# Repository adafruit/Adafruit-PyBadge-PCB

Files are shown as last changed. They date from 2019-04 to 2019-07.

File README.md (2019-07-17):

## Adafruit PyBadge PCB

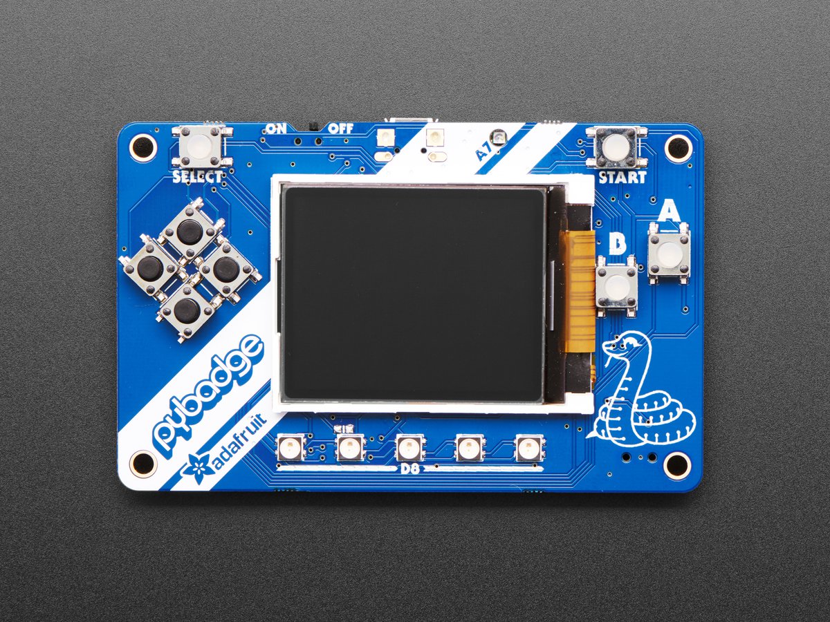
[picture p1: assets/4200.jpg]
<a href="http://www.adafruit.com/products/4200"><br/>
Click here to purchase one from the Adafruit shop</a>

PCB files for the Adafruit PyBadge. 

Format is EagleCAD schematic and board layout
* https://www.adafruit.com/product/4200

### Description

What's the size of a credit card and can run CircuitPython, MakeCode Arcade or Arduino? That's right, its the **Adafruit PyBadge!** We wanted to see how much we could cram into a 3 3⁄8 × 2 1⁄8 inch rounded rectangle, to make an all-in-one dev board with a lot of possibilities, and this is what we came up with.

The PyBadge is a compact board, like we said, it's credit card sized. It's powered by our favorite chip, the ATSAMD51, with 512KB of flash and 192KB of RAM. We add 2 MB of QSPI flash for file storage, handy for images, fonts, sounds, or game assets.

On the front you get a 1.8" 160x128 color TFT display with dimmable backlight - we have fast DMA support for drawing so updates are incredibly fast. There's also 8 silicone-top buttons, they are clicky but have a soft button top so they're nice and grippy. The buttons are arranged to mimic a gaming handheld, with a d-pad, 2 menu-select buttons and 2 fire-action buttons. There's also 5 NeoPixel LEDs to dazzle or track activity.

On the back we have a full Feather-compatible header socket set, so you can plug in any FeatherWing to expand the capabilities of the PyBadge. There's also 3 STEMMA connectors - two 3-pin with ADC/PWM capability and one 4-pin that connects to I2C - you can use this for Grove sensors as well.

For built in sensors, there's a light sensor that points out the front, and a 3-axis accelerometer that can detect taps and free-fall. To make bleeps and bloops, there's a built in buzzer-speaker. [For projects where you need more volume, you can plug in one of our 8 ohm speakers](https://www.adafruit.com/product/3923).

[You can power the PyBadge from any of our LiPoly batteries, but we like this 400mAh one](https://www.adafruit.com/product/3898.) An on-off switch will save battery power when not in use. Or power from the Micro USB port - it will also charge up the battery if one is attached.

Now, how to program it? Well you've got a lot of options!

[MakeCode Arcade is the easiest to start for making games](https://arcade.makecode.com/), you can drag-and-drop blocks and load games over the disk-drive bootloader
[CircuitPython](https://circuitpython.org/board/pybadge/) lets you draw graphics, play wave files and print out text in any fonts - all in Python! There's tons of sensor support as well.
Arduino is low level, powerful, but a little more challenging. [You can use Adafruit Arcada](https://github.com/adafruit/Adafruit_Arcada) to interface with the hardware and it will abstract some of the nitty-gritty details like reading buttons for you.
Here's a list of everything you get

 * **ATSAMD51J19** @ 120MHz with 3.3V logic/power - 512KB of FLASH + 192KB of RAM
 * **2 MB of SPI Flash** for storing images, sounds, animations, whatever!
 * **1.8" 160x128 Color TFT Display** connected to its own SPI port
 * **8 x Game/Control Buttons** with nice silicone button tops (these feel great)
 * **5 x NeoPixels** for badge dazzle, or game score-keeping
 * **Triple-axis accelerometer** (motion sensor)
 * **Light sensor**, reverse-mount so that it points out the front
 * **Built in buzzer mini-speaker**
 * **Mono Class-D speaker driver for** 4-8 ohm speakers, up to 2 Watts
 * LiPoly battery port with built in recharging capability
 * USB port for battery charging, programming and debugging
 * Two female header strips with Feather-compatible pinout so you can plug any FeatherWings in
 * JST ports for NeoPixels, sensor input, and I2C (you can fit I2C Grove connectors in here)
 * Reset button
 * On-Off switch

### License

Adafruit invests time and resources providing this open source design, please support Adafruit and open-source hardware by purchasing products from [Adafruit](https://www.adafruit.com)!

Designed by Limor Fried/Ladyada for Adafruit Industries.

Creative Commons Attribution/Share-Alike, all text above must be included in any redistribution. 
See license.txt for additional details.

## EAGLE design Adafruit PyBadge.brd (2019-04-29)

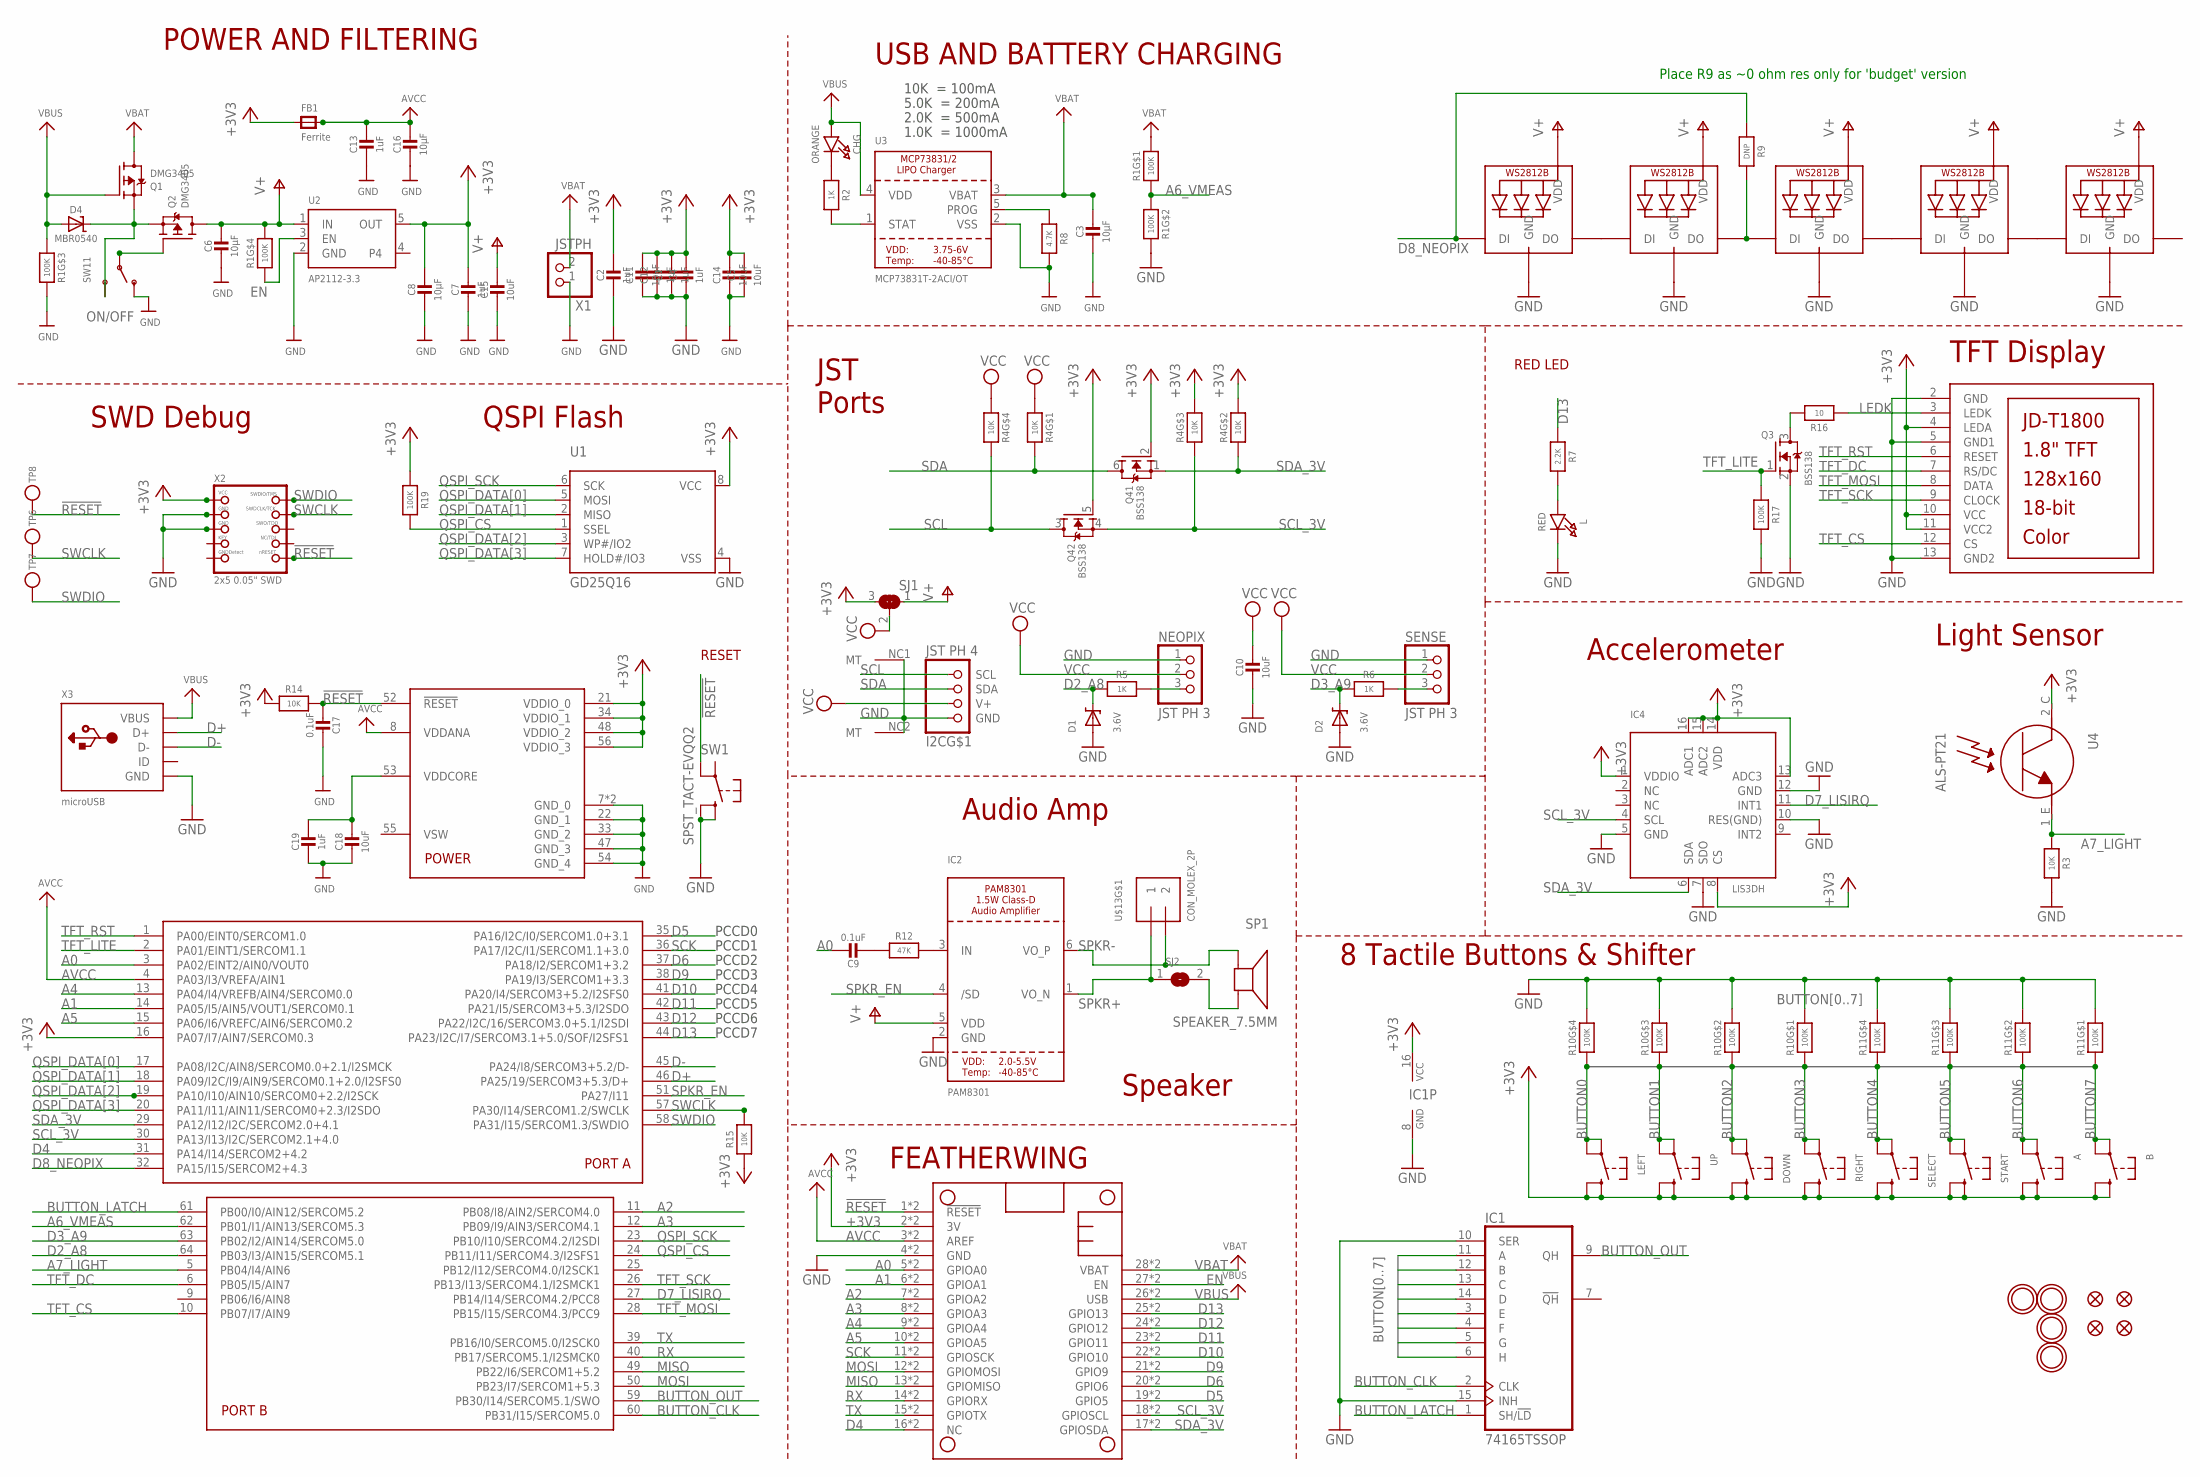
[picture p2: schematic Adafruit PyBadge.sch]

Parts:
A: SWITCH_TACT_SMT_6MMSMALL; 6MM_SMT
B: SWITCH_TACT_SMT_6MMSMALL; 6MM_SMT
C1, C2, C4, C7, C12, C13, C19: 1uF; 0603-NO
C3, C6, C8: 10µF; 0805-NO
C5, C10, C11, C14, C15, C18: 10uF; 0805-NO
C9, C17: 0.1uF; 0603-NO
C16: 10µF; _0805MP
CHG: ORANGE; CHIPLED_0805_NOOUTLINE
D1, D2: 3.6V; SOD-323
D4: MBR0540; SOD-123
DOWN: SWITCH_TACT_SMT_6MMSMALL; 6MM_SMT
FB1: Ferrite; 0805-NO
I2C: JST PH 4; JSTPH4
IC1: 74165TSSOP; TSSOP16
IC2: PAM8301; SOT23-6
IC4: LIS3DH; LGA16_3X3MM
L: RED; CHIPLED_0805_NOOUTLINE
LCD1: DISP_LCD_JDT1800; JD-T1800
LED1, LED2, LED3, LED4, LED5: WS2812B3535; LED3535
LEFT: SWITCH_TACT_SMT_6MMSMALL; 6MM_SMT
MS1: FEATHERWING_SMTDUALNOHOLES; FEATHERWING_SMT_NOHOLES
NEOPIX: JST PH 3; JSTPH3
Q1, Q2: DMG3405; SOT23-R
Q3: BSS138; SOT23-WIDE
Q4: BSS138; SOT363
R1, R10, R11: 100K; RESPACK_4X0603
R2, R5, R6: 1K; 0603-NO
R3, R14, R15: 10K; 0603-NO
R4: 10K; RESPACK_4X0603
R7: 2.2K; 0603-NO
R8: 4.7K; 0603-NO
R9: DNP; 0603-NO
R12: 47K; 0603-NO
R16: 10; 0603-NO
R17, R19: 100K; 0603-NO
RIGHT: SWITCH_TACT_SMT_6MMSMALL; 6MM_SMT
SELECT: SWITCH_TACT_SMT_6MMSMALL; 6MM_SMT
SENSE: JST PH 3; JSTPH3
SJ1: SOLDERJUMPER_2WAY; SOLDERJUMPER_2WAY_OPEN_NOPASTE
SJ2: SOLDERJUMPERCLOSED; SOLDERJUMPER_CLOSEDWIRE
SP1: SPEAKER_7.5MM; BUZZER_SMT_7.5MM
START: SWITCH_TACT_SMT_6MMSMALL; 6MM_SMT
SW1: SPST_TACT-EVQQ2; EVQ-Q2_SMALLER
SW11: SWITCH_SPDT; SPDT_SMT_SSSS811101
TP6, TP7, TP8: TESTPOINTROUND2MM; TESTPOINT_ROUND_2MM
U1: GD25Q16; SOIC8_208MIL
U2: AP2112-3.3; SOT23-5
U3: MCP73831T-2ACI/OT; SOT23-5
U4: ALS-PT21; ALS-PT26-21C
U$5, U$6, U$15, U$17: MOUNTINGHOLE3.0THIN; MOUNTINGHOLE_3.0_PLATEDTHIN
U$13: CON_MOLEX_2P; 53398-0271
U$24: ATSAMD51J19; PQFN64-1
U$34, U$35, U$42, U$43: FIDUCIAL_1MM
UP: SWITCH_TACT_SMT_6MMSMALL; 6MM_SMT
X1: JSTPH; JSTPH2
X2: 2x5 0.05" SWD; 2X05_1.27MM_BOX_POSTS
X3: microUSB; 4UCONN_20329_V2

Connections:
!RESET: C17.2, MS1.1 (!RESET), MS1.1B (!RESET), R14.2, SW1.A' (P1), TP8.P$1, U$24.52 (!RESET), X2.10 (NRESET)
+3V3: A.B (S), A.B' (S1), B.B (S), B.B' (S1), C1.1, C2.1, C4.1, C5.1, C7.1, C8.1, C11.1, C12.1, C14.1, DOWN.B (S), DOWN.B' (S1), FB1.1, IC1.16 (VCC), IC4.1 (VDDIO), IC4.8 (CS), IC4.13 (ADC3), IC4.14 (VDD), IC4.15 (ADC2), IC4.16 (ADC1), LCD1.4 (LEDA), LCD1.10 (VCC), LCD1.11 (VCC2), LEFT.B (S), LEFT.B' (S1), MS1.2 (3V), MS1.2B (3V), Q4.2 (G), Q4.5 (G), R4.2 (1), R4.3 (1), R14.1, R15.1, R19.1, RIGHT.B (S), RIGHT.B' (S1), SELECT.B (S), SELECT.B' (S1), SJ1.3, START.B (S), START.B' (S1), U1.8 (VCC), U2.5 (OUT), U4.2_C (C), U$24.16 (PA07/I7/AIN7/SERCOM0.3), U$24.21 (VDDIO_0), U$24.34 (VDDIO_1), U$24.48 (VDDIO_2), U$24.56 (VDDIO_3), UP.B (S), UP.B' (S1), X2.1 (VCC)
A0: C9.1, MS1.5 (GPIOA0), MS1.5B (GPIOA0), U$24.3 (PA02/EINT2/AIN0/VOUT0)
A1: MS1.6 (GPIOA1), MS1.6B (GPIOA1), U$24.14 (PA05/I5/AIN5/VOUT1/SERCOM0.1)
A2: MS1.7 (GPIOA2), MS1.7B (GPIOA2), U$24.11 (PB08/I8/AIN2/SERCOM4.0)
A3: MS1.8 (GPIOA3), MS1.8B (GPIOA3), U$24.12 (PB09/I9/AIN3/SERCOM4.1)
A4: MS1.9 (GPIOA4), MS1.9B (GPIOA4), U$24.13 (PA04/I4/VREFB/AIN4/SERCOM0.0)
A5: MS1.10 (GPIOA5), MS1.10B (GPIOA5), U$24.15 (PA06/I6/VREFC/AIN6/SERCOM0.2)
A6_VMEAS: R1.1, R1.2 (1), U$24.62 (PB01/I1/AIN13/SERCOM5.3)
A7_LIGHT: R3.2, U4.1_E (E), U$24.5 (PB04/I4/AIN6)
AVCC: C13.1, C16.1, FB1.2, MS1.3 (AREF), MS1.3B (AREF), U$24.4 (PA03/I3/VREFA/AIN1), U$24.8 (VDDANA)
BUTTON0: IC1.11 (A), LEFT.A, LEFT.A' (P1), R10.4 (1)
BUTTON1: IC1.12 (B), R10.3 (1), UP.A, UP.A' (P1)
BUTTON2: DOWN.A, DOWN.A' (P1), IC1.13 (C), R10.2 (1)
BUTTON3: IC1.14 (D), R10.1, RIGHT.A, RIGHT.A' (P1)
BUTTON4: IC1.3 (E), R11.4 (1), SELECT.A, SELECT.A' (P1)
BUTTON5: IC1.4 (F), R11.3 (1), START.A, START.A' (P1)
BUTTON6: A.A, A.A' (P1), IC1.5 (G), R11.2 (1)
BUTTON7: B.A, B.A' (P1), IC1.6 (H), R11.1
BUTTON_CLK: IC1.2 (CLK), U$24.60 (PB31/I15/SERCOM5.0)
BUTTON_LATCH: IC1.1 (SH/!LD), U$24.61 (PB00/I0/AIN12/SERCOM5.2)
BUTTON_OUT: IC1.9 (QH), U$24.59 (PB30/I14/SERCOM5.1/SWO)
CHG_LED: R2.2, U3.1 (STAT)
CHG_RATE: R8.1, U3.5 (PROG)
D2_: NEOPIX.3, R5.1
D2_A8: D1.C, R5.2, U$24.64 (PB03/I3/AIN15/SERCOM5.1)
D3_: R6.1, SENSE.3
D3_A9: D2.C, R6.2, U$24.63 (PB02/I2/AIN14/SERCOM5.0)
D4: MS1.16 (NC), MS1.16B (NC), U$24.31 (PA14/I14/SERCOM2+4.2)
D5: MS1.19 (GPIO5), MS1.19B (GPIO5), U$24.35 (PA16/I2C/I0/SERCOM1.0+3.1)
D6: MS1.20 (GPIO6), MS1.20B (GPIO6), U$24.37 (PA18/I2/SERCOM1+3.2)
D7_LISIRQ: IC4.11 (INT1), U$24.27 (PB14/I14/SERCOM4.2/PCC8)
D8_NEOPIX: LED1.1 (DI), R9.1, U$24.32 (PA15/I15/SERCOM2+4.3)
D9: MS1.21 (GPIO9), MS1.21B (GPIO9), U$24.38 (PA19/I3/SERCOM1+3.3)
D10: MS1.22 (GPIO10), MS1.22B (GPIO10), U$24.41 (PA20/I4/SERCOM3+5.2/I2SFS0)
D11: MS1.23 (GPIO11), MS1.23B (GPIO11), U$24.42 (PA21/I5/SERCOM3+5.3/I2SDO)
D12: MS1.24 (GPIO12), MS1.24B (GPIO12), U$24.43 (PA22/I2C/16/SERCOM3.0+5.1/I2SDI)
D13: MS1.25 (GPIO13), MS1.25B (GPIO13), R7.1, U$24.44 (PA23/I2C/I7/SERCOM3.1+5.0/SOF/I2SFS1)
D+: U$24.46 (PA25/19/SERCOM3+5.3/D+), X3.D+
D-: U$24.45 (PA24/I8/SERCOM3+5.2/D-), X3.D-
EN: MS1.27 (EN), MS1.27B (EN), R1.4 (1), U2.3 (EN)
GND: C1.2, C2.2, C3.2, C4.2, C5.2, C6.2, C7.2, C8.2, C10.2, C11.2, C12.2, C13.2, C14.2, C15.2, C16.2, C17.1, C18.2, C19.2, D1.A, D2.A, I2C.1 (GND), I2C.NC1 (MT), I2C.NC2 (MT), IC1.8 (GND), IC1.10 (SER), IC1.15 (INH), IC2.2 (GND), IC4.5 (GND), IC4.7 (SDO), IC4.10 (RES(GND)), IC4.12 (GND), L.C, LCD1.2 (GND), LCD1.5 (GND1), LCD1.13 (GND2), LED1.4 (GND), LED2.4 (GND), LED3.4 (GND), LED4.4 (GND), LED5.4 (GND), MS1.4 (GND), MS1.4B (GND), NEOPIX.1, Q3.2 (S), R1.6 (2), R1.7 (2), R3.1, R8.2, R10.5 (2), R10.6 (2), R10.7 (2), R10.8 (2), R11.5 (2), R11.6 (2), R11.7 (2), R11.8 (2), R17.2, SENSE.1, SW1.B (S), SW1.B' (S1), SW11.A (O), U1.4 (VSS), U2.2 (GND), U3.2 (VSS), U$24.7 (GND_0), U$24.22 (GND_1), U$24.33 (GND_2), U$24.47 (GND_3), U$24.54 (GND_4), U$24.EXP (GND_0), X1.1, X2.3 (GND), X2.5 (GND), X3.BASE@1 (GND), X3.BASE@2 (GND), X3.GND, X3.SPRT@1 (GND), X3.SPRT@2 (GND), X3.SPRT@3 (GND), X3.SPRT@4 (GND)
LEDK: LCD1.3 (LEDK), R16.1
MISO: MS1.13 (GPIOMISO), MS1.13B (GPIOMISO), U$24.49 (PB22/I6/SERCOM1+5.2)
MOSI: MS1.12 (GPIOMOSI), MS1.12B (GPIOMOSI), U$24.50 (PB23/I7/SERCOM1+5.3)
unnamed: CHG.C, R2.1
unnamed: L.A, R7.2
unnamed: LED1.3 (DO), LED2.1 (DI)
unnamed: LED2.3 (DO), LED3.1 (DI), R9.2
unnamed: LED3.3 (DO), LED4.1 (DI)
unnamed: Q3.3 (D), R16.2
unnamed: LED4.3 (DO), LED5.1 (DI)
unnamed: D4.C, Q1.2 (S), Q2.2 (S), SW11.C (S)
unnamed: C9.2, R12.1
unnamed: IC2.3 (IN), R12.2
unnamed: SJ2.2, SP1.-
ON/OFF: Q2.1 (G), SW11.B
QSPI_CS: R19.2, U1.1 (SSEL), U$24.24 (PB11/I11/SERCOM4.3/I2SFS1)
QSPI_DATA[0]: U1.5 (MOSI), U$24.17 (PA08/I2C/AIN8/SERCOM0.0+2.1/I2SMCK)
QSPI_DATA[1]: U1.2 (MISO), U$24.18 (PA09/I2C/I9/AIN9/SERCOM0.1+2.0/I2SFS0)
QSPI_DATA[2]: U1.3 (WP#/IO2), U$24.19 (PA10/I10/AIN10/SERCOM0+2.2/I2SCK)
QSPI_DATA[3]: U1.7 (HOLD#/IO3), U$24.20 (PA11/I11/AIN11/SERCOM0+2.3/I2SDO)
QSPI_SCK: U1.6 (SCK), U$24.23 (PB10/I10/SERCOM4.2/I2SDI)
RX: MS1.14 (GPIORX), MS1.14B (GPIORX), U$24.40 (PB17/SERCOM5.1/I2SMCK0)
SCK: MS1.11 (GPIOSCK), MS1.11B (GPIOSCK), U$24.36 (PA17/I2C/I1/SERCOM1.1+3.0)
SCL: I2C.4 (SCL), Q4.3 (D), R4.5 (2)
SCL_3V: IC4.4 (SCL), MS1.18 (GPIOSCL), MS1.18B (GPIOSCL), Q4.4 (S), R4.6 (2), U$24.30 (PA13/I13/I2C/SERCOM2.1+4.0)
SDA: I2C.3 (SDA), Q4.6 (D), R4.8 (2)
SDA_3V: IC4.6 (SDA), MS1.17 (GPIOSDA), MS1.17B (GPIOSDA), Q4.1 (S), R4.7 (2), U$24.29 (PA12/I12/I2C/SERCOM2.0+4.1)
SPKR+: IC2.1 (VO_N), SJ2.1, U$13.1
SPKR-: IC2.6 (VO_P), SP1.+, U$13.2
SPKR_EN: IC2.4 (/SD), U$24.51 (PA27/I11)
SWCLK: R15.2, TP6.P$1, U$24.57 (PA30/I14/SERCOM1.2/SWCLK), X2.4 (SWDCLK)
SWDIO: TP7.P$1, U$24.58 (PA31/I15/SERCOM1.3/SWDIO), X2.2 (SWDIO)
TFT_CS: LCD1.12 (CS), U$24.10 (PB07/I7/AIN9)
TFT_DC: LCD1.7 (RS/DC), U$24.6 (PB05/I5/AIN7)
TFT_LITE: Q3.1 (G), R17.1, U$24.2 (PA01/EINT1/SERCOM1.1)
TFT_MOSI: LCD1.8 (DATA), U$24.28 (PB15/I15/SERCOM4.3/PCC9)
TFT_RST: LCD1.6 (RESET), U$24.1 (PA00/EINT0/SERCOM1.0)
TFT_SCK: LCD1.9 (CLOCK), U$24.26 (PB13/I13/SERCOM4.1/I2SMCK1)
TX: MS1.15 (GPIOTX), MS1.15B (GPIOTX), U$24.39 (PB16/I0/SERCOM5.0/I2SCK0)
V+: C6.1, C15.1, IC2.5 (VDD), LED1.2 (VDD), LED2.2 (VDD), LED3.2 (VDD), LED4.2 (VDD), LED5.2 (VDD), Q2.3 (D), R1.5 (2), SJ1.1, U2.1 (IN)
VBAT: C3.1, MS1.28 (VBAT), MS1.28B (VBAT), Q1.3 (D), R1.8 (2), U3.3 (VBAT), X1.2
VBUS: CHG.A, D4.A, MS1.26 (USB), MS1.26B (USB), Q1.1 (G), R1.3 (1), U3.4 (VDD), X3.VBUS
VCC: C10.1, I2C.2 (V+), NEOPIX.2, R4.1, R4.4 (1), SENSE.2, SJ1.2
VDDCORE2: C18.1, C19.1, U$24.53 (VDDCORE)

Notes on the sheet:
POWER AND FILTERING
RESET
10K = 100mA
5.0K = 200mA
2.0K = 500mA
1.0K = 1000mA
USB AND BATTERY CHARGING
RED LED
Accelerometer
Light Sensor
FEATHERWING
TFT Display
Audio Amp
JST Ports
PCCD0
PCCD1
PCCD2
PCCD3
PCCD4
PCCD5
PCCD6
PCCD7
Speaker
Place R9 as ~0 ohm res only for 'budget' version
8 Tactile Buttons & Shifter
SWD Debug
QSPI Flash

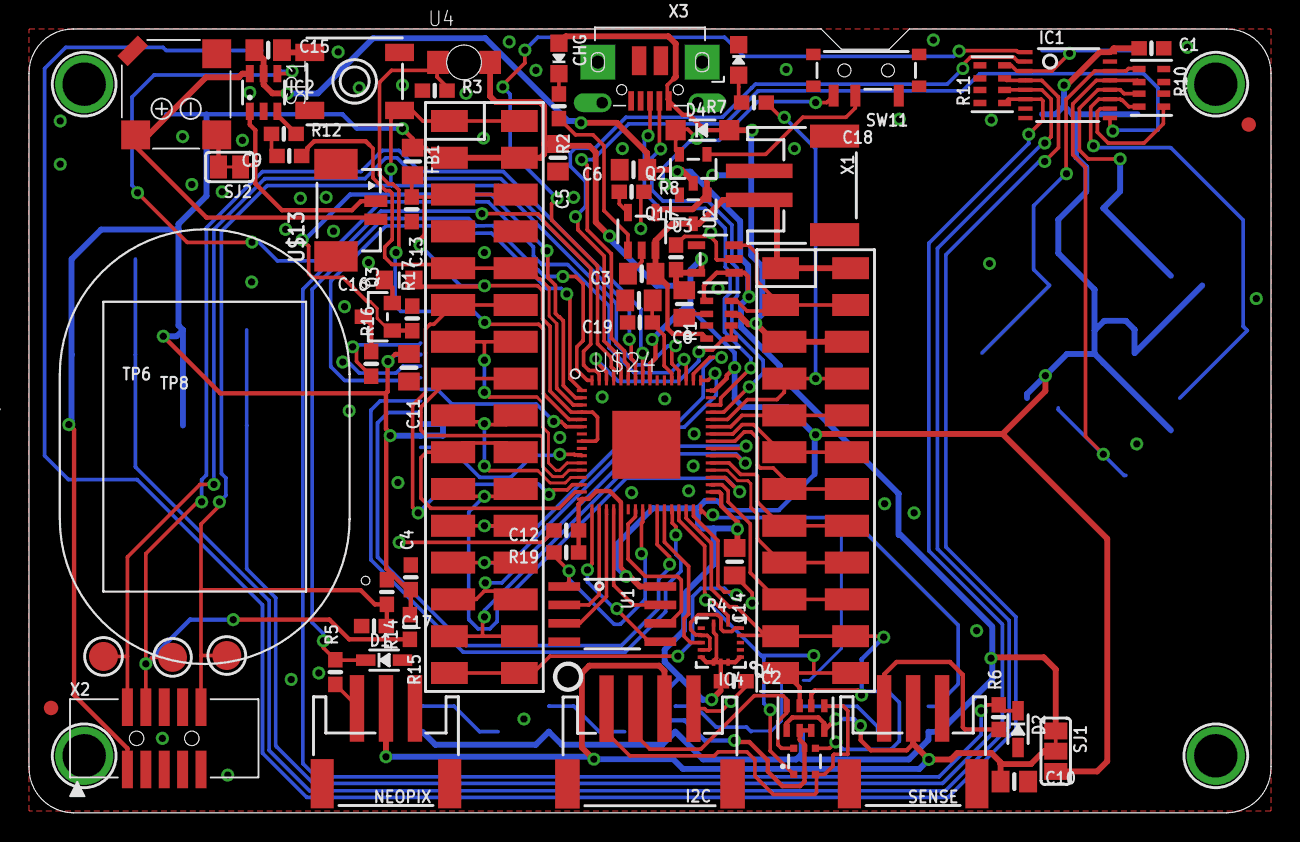
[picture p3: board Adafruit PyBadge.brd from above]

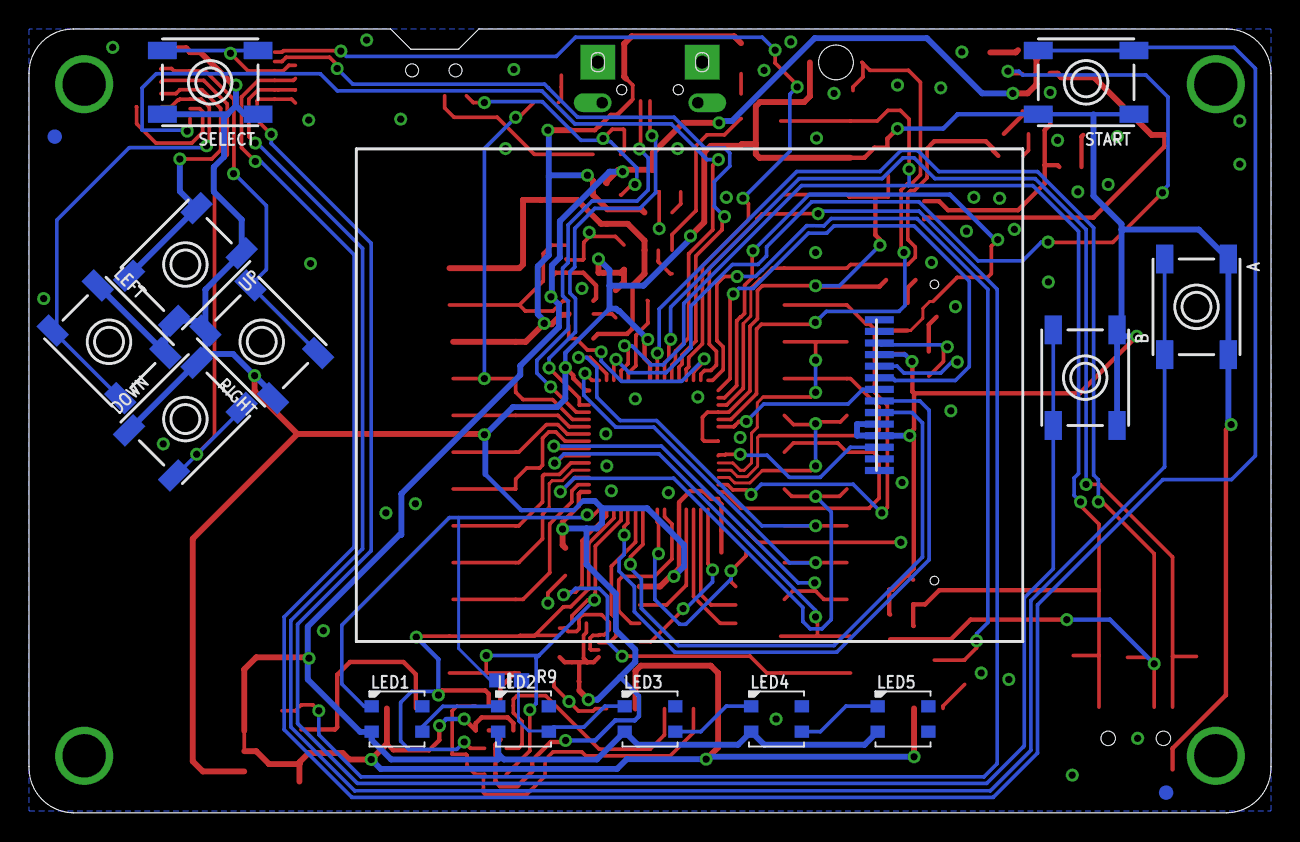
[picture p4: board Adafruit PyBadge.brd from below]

Board: 2 copper layers, 85.7 x 54.1 mm, 96 parts (18 on the bottom side), 86 nets.

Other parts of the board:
U$8: SPEAKER_OVAL8OHM
U$18: PYBADGE_TOP
U$32: PYBADGE_BOT
U$37: PCBFEAT-REV-040

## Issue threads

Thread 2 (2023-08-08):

BOM for the PyBadge / EdgeBadge?

technobly, 2023-08-08:
> README.md:
>
> 8 x Game/Control Buttons with nice silicone button tops (these feel great)

I'm looking for the tactile switches used on these badges, they do indeed feel great!

Is there a BOM for these with the part number, or any hints on where to get these?  I did find some at Digi-key, but not quite the same. https://forums.adafruit.com/viewtopic.php?p=981850#p981850

ladyada, 2023-08-09:
our part is LAXXSCOM 8EBB-C-B-S9-03-5, admittedly not available anywhere easily
can you use something like https://www.adafruit.com/product/3983 instead? they are available on aliexpress and such

technobly, 2023-08-09:
Thanks for the info, and I'll check out that other button as well!

technobly, 2023-08-10:
@ladyada it seems that LAXXSCOM part might be something else?  Don't see a rubber switch option here and they claim they don't make one with a silicone top:
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

However I found the second one at LCSC which is nice.

I wish you carried that EdgeBadge button in your store in SMT format.  I do see you have it in TH: https://www.adafruit.com/product/4183

If you come across the part number, please let me know ;-)  TIA!

technobly, 2023-08-14:
That looks like the right one, thank you very much :D

Closed 2023-08-09.

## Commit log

2019-04-29 Adding PCB files
    [Adafrfuit PyBadge.sch, Adafruit PyBadge.brd]
2019-07-17 updated to use cookiecutter for pcb repos
2019-07-24 fix typo
    [Adafruit PyBadge.sch]

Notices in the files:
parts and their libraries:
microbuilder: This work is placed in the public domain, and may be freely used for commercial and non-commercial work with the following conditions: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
